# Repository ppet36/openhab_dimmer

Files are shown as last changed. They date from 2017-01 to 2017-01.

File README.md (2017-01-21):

# OpenHAB dimmer(s)

This repository contains simple dimmers for LED lighting based on potentiometer or cheap
chinese RF LED controller such as
http://www.ebay.com/itm/Mini-12V-RF-Wireless-Remote-Switch-Controller-Dimmer-for-LED-Strip-Light.

As always is there Cadsoft's Eagle schematic, PCB and firmware for ESP8266 that can be programmed using Arduino IDE.
Potentiometer version uses Average library https://github.com/MajenkoLibraries/Average for nice fade efect and jitter elimination.

Both dimmers are based on MOSFET transistor at output and cheap DC/DC converter with LM2596 from eBay (set at 3.3V!!!) for powering ESP.
In my case i used IPA040N06N with 0.004ohm resistance in threshold state. PWM frequency is set only to 120Hz so any MOSFET with
reasonable parameters can be used.

Like other my OpenHAB projects is there set of default parameters in firmare as well as HTML configuration interface at IP address of device.

## Potentiometer version
Potentiometer version uses in my case slider potentiometer and ESP07 with ADC input.
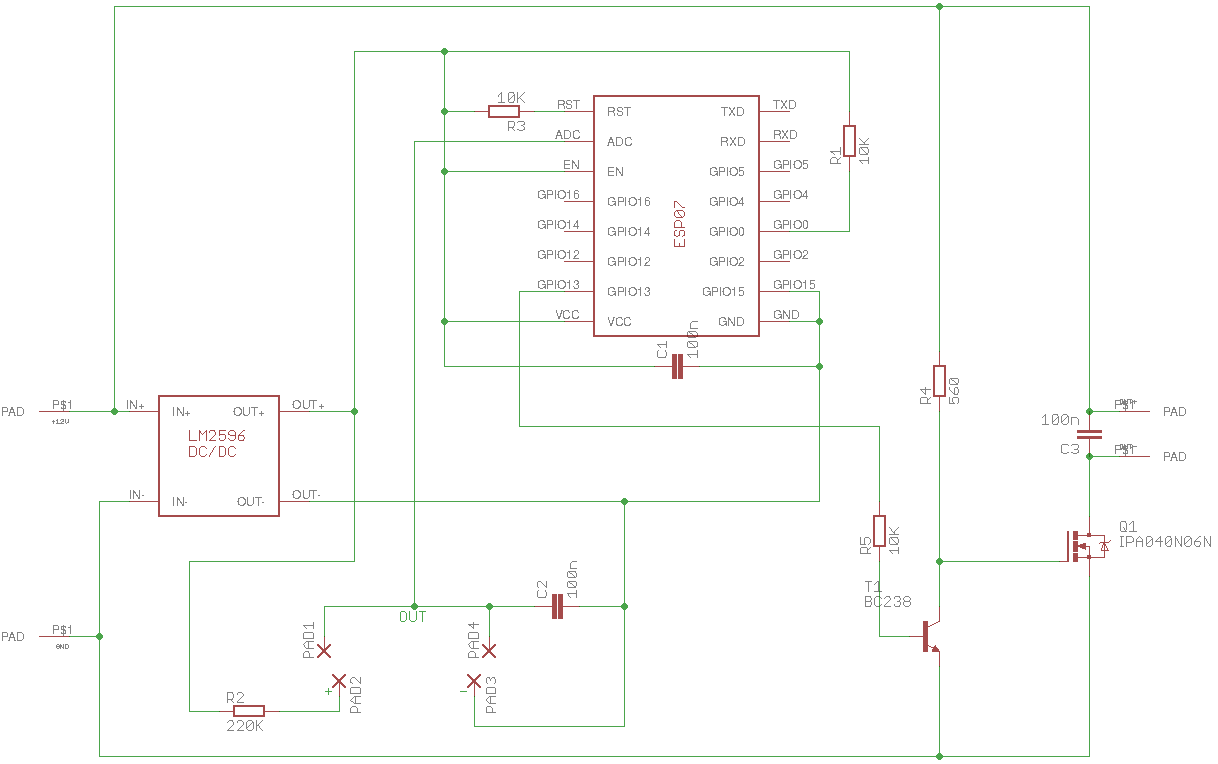
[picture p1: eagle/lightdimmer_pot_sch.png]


## RF version
RF version uses standard receiver available from eBay such as http://www.ebay.com/sch/i.html?_nkw=433mhz+receiver. Remote control codes can be set in firmware. This version uses my favorite ESP01 :)
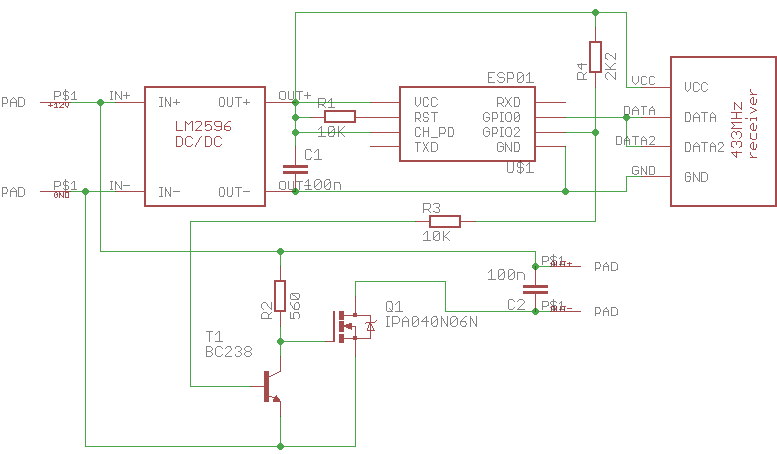
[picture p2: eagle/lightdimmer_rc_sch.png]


## Some project images
### RF version
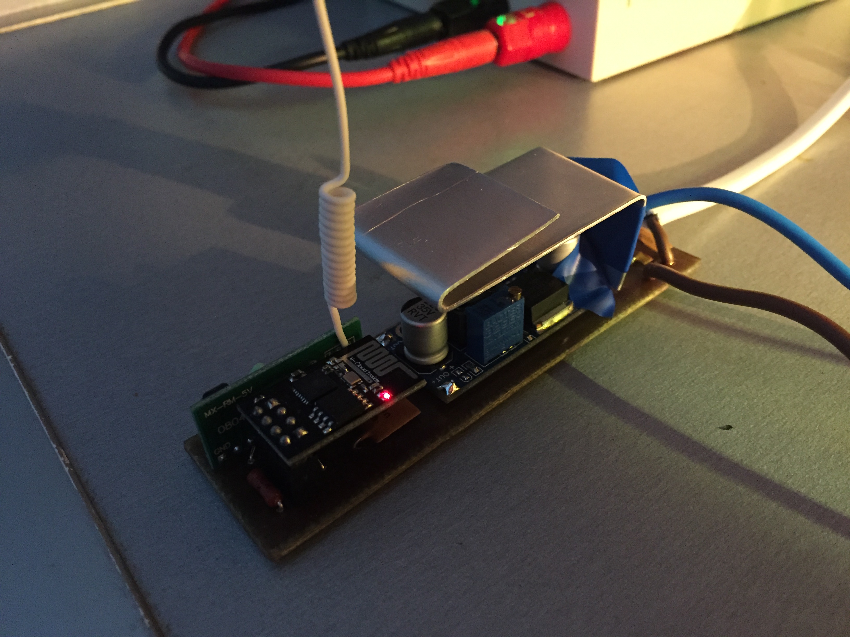
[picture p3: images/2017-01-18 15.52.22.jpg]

### POT version
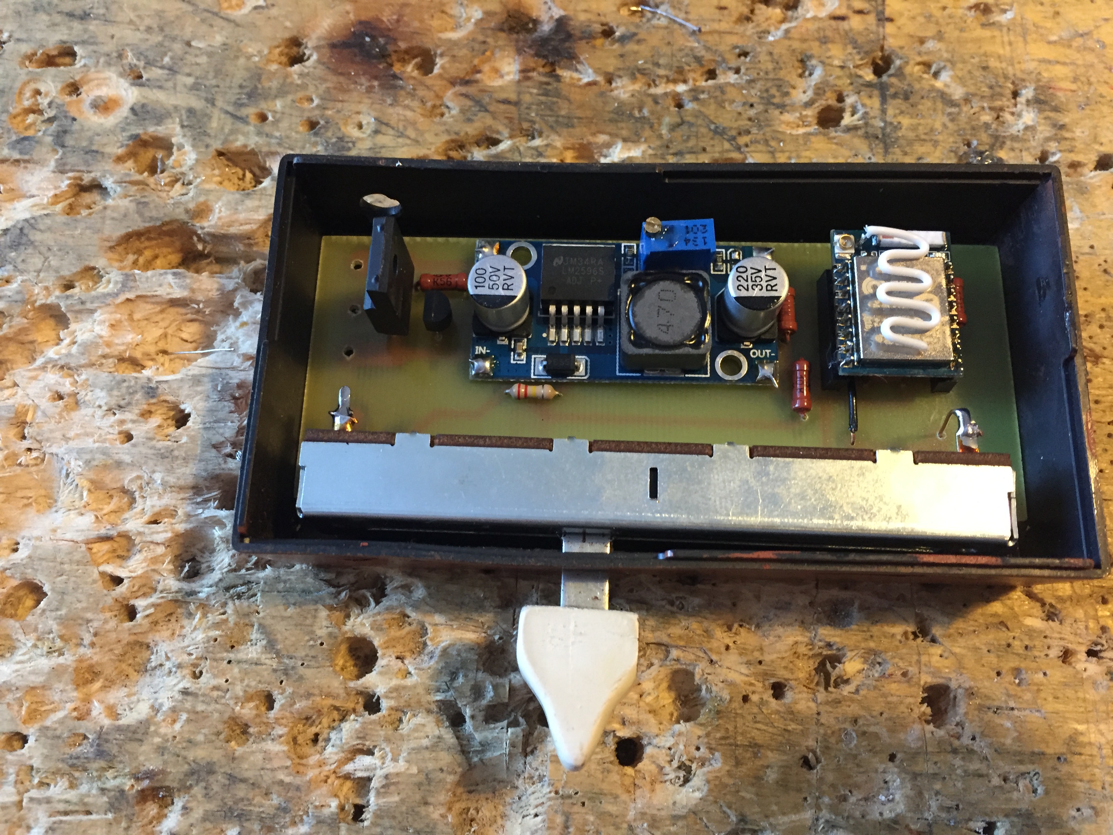
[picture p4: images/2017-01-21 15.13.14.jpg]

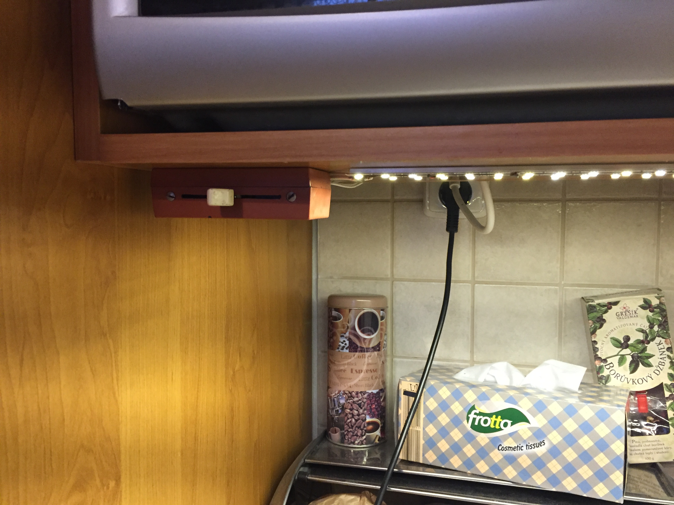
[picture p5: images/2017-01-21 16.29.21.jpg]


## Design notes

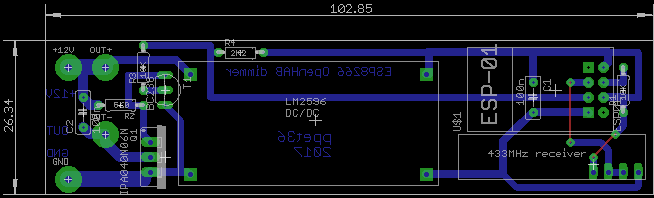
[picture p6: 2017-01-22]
eagle/lightdimmer_rc_brd.png

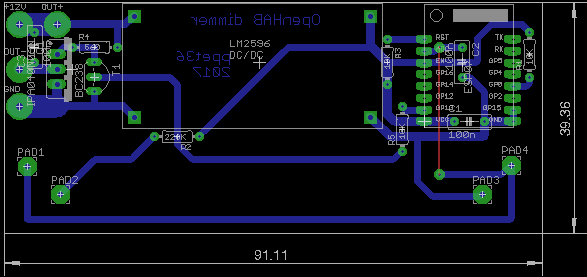
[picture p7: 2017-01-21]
eagle/lightdimmer_pot_brd.png

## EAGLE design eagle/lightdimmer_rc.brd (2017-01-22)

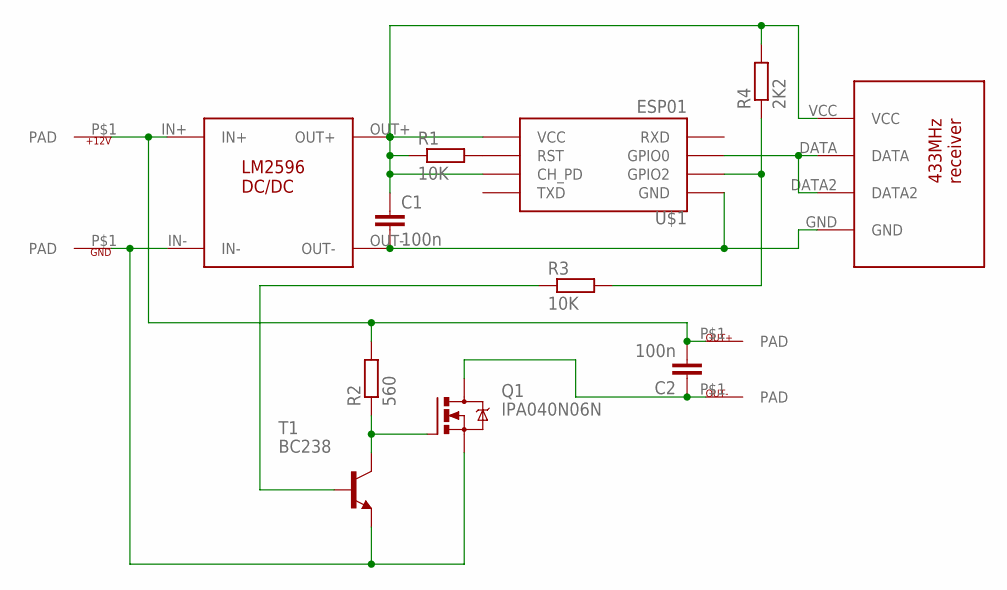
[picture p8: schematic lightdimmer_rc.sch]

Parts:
+12V: PAD
C1, C2: 100n; C050-025X075
GND: PAD
OUT+: PAD
OUT-: PAD
Q1: IPA040N06N; TO220BV
R1, R3: 10K; 0204/7
R2: 560; 0204/7
R4: 2K2; 0204/7
T1: BC238; TO92-CBE
U$1: ESP01
U$2: RECV433MHZ
U$3: LM2596DCDC

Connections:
unnamed: C1.1, R1.1, R4.2, U$1.CH_PD, U$1.VCC, U$2.VCC, U$3.OUT+
unnamed: C1.2, U$1.GND, U$2.GND, U$3.OUT-
unnamed: U$1.GPIO0, U$2.DATA, U$2.DATA2
unnamed: C2.1, OUT-.P$1, Q1.D
unnamed: GND.P$1, Q1.S, T1.E, U$3.IN-
unnamed: Q1.G, R2.1, T1.C
unnamed: +12V.P$1, C2.2, OUT+.P$1, R2.2, U$3.IN+
unnamed: R3.2, R4.1, U$1.GPIO2
unnamed: R1.2, U$1.RST
unnamed: R3.1, T1.B

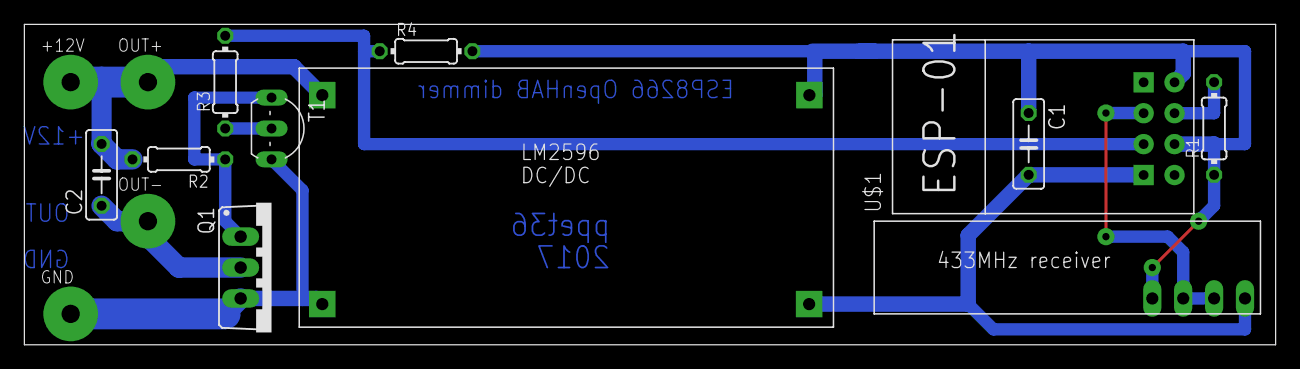
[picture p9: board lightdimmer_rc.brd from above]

Board: 2 copper layers, 102.8 x 26.3 mm, 15 parts (0 on the bottom side), 10 nets.

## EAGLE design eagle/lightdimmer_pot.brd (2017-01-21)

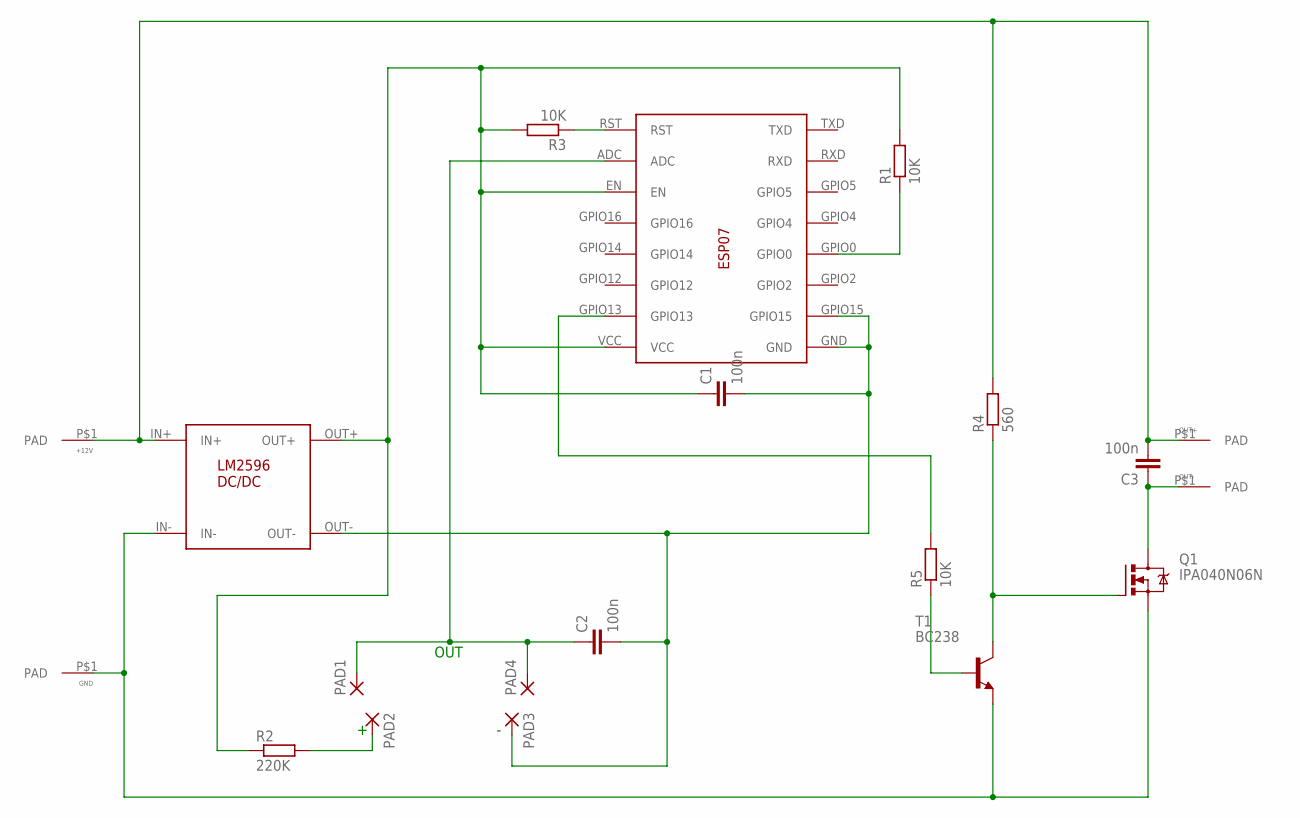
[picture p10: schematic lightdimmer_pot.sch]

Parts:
+12V: PAD
C1, C2, C3: 100n; C050-025X075
GND: PAD
OUT+: PAD
OUT-: PAD
PAD1, PAD2, PAD3, PAD4: WIREPAD3,17/1,1; 3,17/1,1
Q1: IPA040N06N; TO220BV
R1, R3, R5: 10K; 0204/7
R2: 220K; 0204/7
R4: 560; 0204/7
T1: BC238; TO92-CBE
U$1: LM2596DCDC
U$2: ESP07

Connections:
unnamed: GND.P$1, Q1.S, T1.E, U$1.IN-
unnamed: +12V.P$1, C3.2, OUT+.P$1, R4.2, U$1.IN+
unnamed: C3.1, OUT-.P$1, Q1.D
unnamed: C1.2, C2.2, PAD3.1, U$1.OUT-, U$2.GND, U$2.GPIO15
unnamed: C1.1, R1.2, R2.1, R3.2, U$1.OUT+, U$2.EN, U$2.VCC
unnamed: R5.2, U$2.GPIO13
unnamed: Q1.G, R4.1, T1.C
unnamed: C2.1, PAD1.1, PAD4.1, U$2.ADC
unnamed: R1.1, U$2.GPIO0
unnamed: R5.1, T1.B
unnamed: PAD2.1, R2.2
unnamed: R3.1, U$2.RST

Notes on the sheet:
OUT

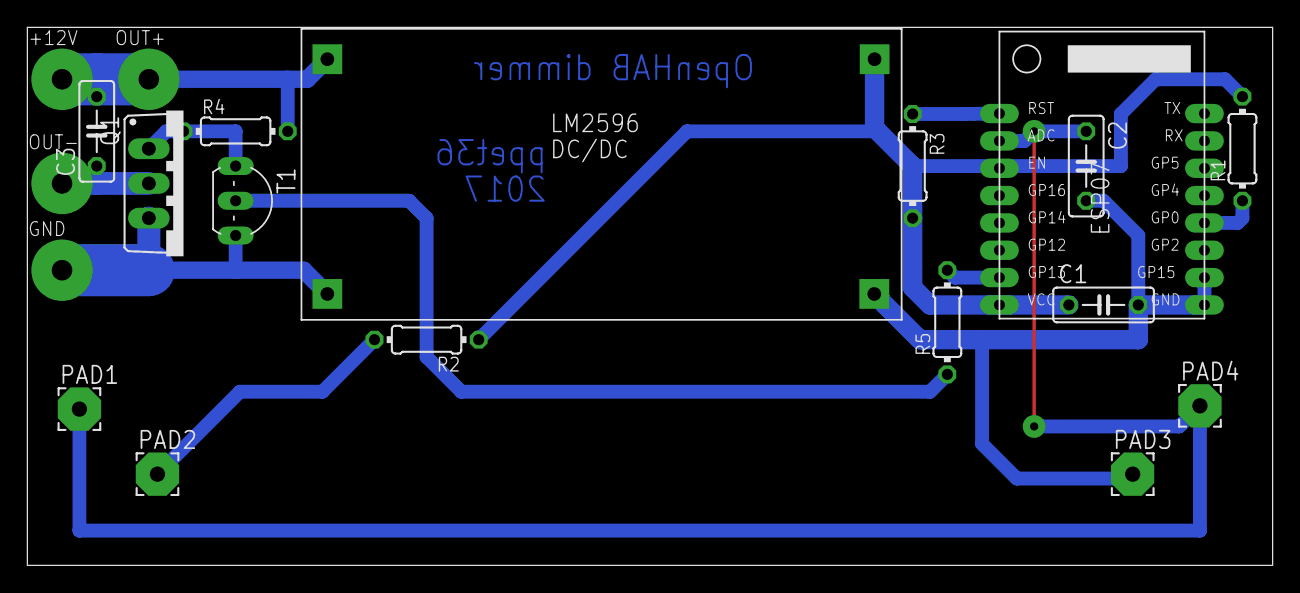
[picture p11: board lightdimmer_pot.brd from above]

Board: 2 copper layers, 91.1 x 39.4 mm, 20 parts (0 on the bottom side), 12 nets.

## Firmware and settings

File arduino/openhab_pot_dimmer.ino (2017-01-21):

/**
 * Simple OpenHAB dimmer based on ESP8266-07 module and potentiometer.
*/
#include <EEPROM.h>
#include <ESP8266WiFi.h>
#include <ESP8266HTTPClient.h>
#include <WiFiClient.h>
#include <ESP8266WebServer.h>
#include "Average.h"

// PIN, which is connected middle of potentiometer
#define POT_PIN  A0
// PWM adjusted pin which is connected to MOSFET gate.
#define PWM_PIN  13

// Local base URL of OpenHAB (can be changed later on config page)
#define DEFAULT_OPENHAB_HOST "192.168.128.100"
#define DEFAULT_OPENHAB_PORT 9000

// Name of OpenHAB item (can be changed later on config page)
#define DEFAULT_OPENHAB_ITEM "kitchenSideboard"

// Update time for item state in seconds;
// dimmer sends periodically its state to OpenHAB
#define ITEM_UPDATE_TIME 60L

// Local network definition; must have static IP address
#define LOCAL_IP   IPAddress(192, 168, 128, 204)
#define GATEWAY    IPAddress(192, 168, 128, 1)
#define SUBNETMASK IPAddress(255, 255, 255, 0)

// Local Wifi AP for connect
#define DEFAULT_WIFI_AP "******"
#define DEFAULT_WIFI_PASSWORD "*******"

// Error count for reconnect WIFI
#define ERR_COUNT_FOR_RECONNECT 30
#define HTTP_READ_TIMEOUT       10000
#define HTTP_CONNECT_TIMEOUT    5000

// Local WEB server port
#define WEB_SERVER_PORT 80

// Magic for detecting empty (unconfigured) EEPROM
#define MAGIC 0x44

// PWM frequuency.
#define PWM_FREQUENCY  120

// When potentiometer change value wait X millis before sending it to OpenHAB.
#define DEFAULT_OH_SEND_TIME 1000L

// POT ADC range
#define DEFAULT_MIN_POT_ADC_VAL 10
#define DEFAULT_MAX_POT_ADC_VAL 1020

// Sensitivity of potentiometer. When value is set from OpenHAB this is minimum change to accept value from potentiometer. In percent.
#define DEFAULT_POT_SENSITIVITY 10

// Nummer of values to average potentiometer. Elimitates jitter and added nice fade efect.
#define POT_AVERAGE_SIZE    500

// Configuration server
ESP8266WebServer *server = (ESP8266WebServer *) NULL;

// Number of communication errors
int errorCount = 0;

// Current light value (0-100) from OpenHAB
int openHabPwmVal = 0;

// Real PWM value is from potentiometer (true) or OpenHAB (false)
bool valFromPot = false;

// Last POT value for determining changes
int lastPotVal = -1;

// Averager for potentiometer vals
Average<int> potAv (POT_AVERAGE_SIZE);


/**
 * EEPROM configuration structure.
*/
struct OhConfiguration {
  int magic;
  char apName [24];
  char password [48];
  char openhabItem [50];
  char openhabHost [50];
  unsigned int openhabPort;
  unsigned int potSensitivity;
  unsigned int potMinAdcVal;
  unsigned int potMaxAdcVal;
  unsigned long openhabSendTime;
};

// Configuration
OhConfiguration config;


/**
 * Inicializes firmware.
*/
void setup() {
  Serial.begin (115200);

  // setup potentiometer pin
  pinMode (POT_PIN, INPUT);

  // setup PWM on output pin
  pinMode (PWM_PIN, OUTPUT);
  analogWriteFreq (PWM_FREQUENCY);
  setPwmVal (0);

  // read config from eeprom
  EEPROM.begin (sizeof (OhConfiguration));
  EEPROM.get (0, config);
  if (config.magic != MAGIC) {
    memset (&config, 0, sizeof (OhConfiguration));
    config.magic = MAGIC;
    updateConfigKey (config.apName, 24, String(DEFAULT_WIFI_AP));
    updateConfigKey (config.password, 48, String(DEFAULT_WIFI_PASSWORD));
    updateConfigKey (config.openhabItem, 50, String(DEFAULT_OPENHAB_ITEM));
    updateConfigKey (config.openhabHost, 50, String(DEFAULT_OPENHAB_HOST));
    config.openhabPort = DEFAULT_OPENHAB_PORT;
    config.potMinAdcVal = DEFAULT_MIN_POT_ADC_VAL;
    config.potMaxAdcVal = DEFAULT_MAX_POT_ADC_VAL;
    config.openhabSendTime = DEFAULT_OH_SEND_TIME;
    config.potSensitivity = DEFAULT_POT_SENSITIVITY;
  }

  // connect to WiFi and create HTTP server
  reconnectWifi();
  createServer();

  delay (1000);

  // Send current light state to OpenHAB; initialy is light off
  updateLightState (openHabPwmVal);
}

/**
 * Helper routine; updates config key.
 *
 * @param c key.
 * @param len max length.
 * @param val value.
*/
void updateConfigKey (char *c, int len, String val) {
  memset (c, 0, len);
  sprintf (c, "%s", val.c_str());
}

/**
 * Reconects WIFI.
*/
void reconnectWifi() {
  Serial.println ("WiFi disconnected...");
  WiFi.disconnect();
  String hostname = String("openhab_") + String(config.openhabItem);
  WiFi.hostname (hostname);
  WiFi.config (LOCAL_IP, GATEWAY, SUBNETMASK);
  WiFi.mode (WIFI_STA);
  delay (1000);

  Serial.print ("Connecting to "); Serial.print (WIFI_AP); Serial.print (' ');
  WiFi.begin (config.apName, config.password);
  delay (1000);
  while (WiFi.status() != WL_CONNECTED) {
    yield();
    delay (500);
    Serial.print (".");
  }
  delay (500);
  Serial.println();
  Serial.println ("WiFi connected...");
}

/**
 * Creates HTTP server.
*/
void createServer() {
  if (server) {
    server->close();
    delete server;
    server = NULL;
  }
  
  // ... and run HTTP server for setup
  server = new ESP8266WebServer (LOCAL_IP, WEB_SERVER_PORT);
  server->on ("/", wsConfig);
  server->on ("/update", wsUpdate);
  server->on ("/reconnect", wsReconnect);
  server->onNotFound (wsUpdatePwmLevel);
  server->begin();

  Serial.println ("Created server...");
}

/**
 * Updates PWM level of light
*/
void wsUpdatePwmLevel() {
  yield();
  
  String url = server->uri();

  Serial.println();
  Serial.print ("GET "); Serial.println (url);

  int pom = url.lastIndexOf ('/');
  if (pom > -1) {
    String val = url.substring (pom + 1);

    for (pom = 0; pom < val.length(); pom++) {
      if (!isDigit (val [pom])) {
        server->send (400, "text/plain", "Bad request");
        return;
      }
    }

    int newVal = (int)constrain (val.toInt(), 0, 100);
    Serial.print ("Update light level to "); Serial.print (newVal); Serial.println ('%');
    
    if (openHabPwmVal != newVal) {
      Serial.println ("Setting value from OpenHAB...");
      openHabPwmVal = newVal;
      valFromPot = false;
    }
    
    server->send (200, "text/plain", "");
  } else {
    server->send (404, "text/plain", "Not found");
  }
}

/**
 * Configuration page.
*/
void wsConfig() {
  yield();

  String resp = "<html><head><title>OpenHAB dimmer configuration</title>";
  resp += "<meta name=\"viewport\" content=\"initial-scale=1.0, width = device-width, user-scalable = no\">";
  resp += "</head><body>";
  resp += "<h1>OpenHAB dimmer configuration</h1>";
  resp += "<form method=\"post\" action=\"/update\" id=\"form\">";
  resp += "<table border=\"0\" cellspacing=\"0\" cellpadding=\"5\">";
  resp += "<tr><td>AP SSID:</td><td><input type=\"text\" name=\"apName\" value=\"" + String(config.apName) + "\" maxlength=\"24\"></td><td></td></tr>";
  resp += "<tr><td>AP Password:</td><td><input type=\"password\" name=\"password\" value=\"" + String(config.password) + "\" maxlength=\"48\"></td><td></td></tr>";
  resp += "<tr><td>OpenHAB item:</td><td><input type=\"text\" name=\"openhabItem\" value=\"" + String(config.openhabItem) + "\" maxlength=\"50\"></td><td></td></tr>";
  resp += "<tr><td>OpenHAB IP address:</td><td><input type=\"text\" name=\"openhabHost\" value=\"" + String(config.openhabHost) + "\" maxlength=\"50\"></td><td></td></tr>";
  resp += "<tr><td>OpenHAB port:</td><td><input type=\"text\" name=\"openhabPort\" value=\"" + String(config.openhabPort) + "\"></td><td></td></tr>";
  resp += "<tr><td>Potentiometer sensitivity [%]:</td><td><input type=\"text\" name=\"potSensitivity\" value=\"" + String(config.potSensitivity) + "\"></td><td></td></tr>";
  resp += "<tr><td>Potentiometer MIN ADC value:</td><td><input type=\"text\" name=\"potMinAdcVal\" value=\"" + String(config.potMinAdcVal) + "\"></td><td></td></tr>";
  resp += "<tr><td>Potentiometer MAX ADC value:</td><td><input type=\"text\" name=\"potMaxAdcVal\" value=\"" + String(config.potMaxAdcVal) + "\"></td><td></td></tr>";
  resp += "<tr><td>Millis before sending to OpenHAB:</td><td><input type=\"text\" name=\"openhabSendTime\" value=\"" + String(config.openhabSendTime) + "\"></td><td></td></tr>";

  resp += "<tr><td colspan=\"3\" align=\"center\"><input type=\"submit\" value=\"Save\"></td></tr>";
  resp += "</table></form>";
  resp += "<p><a href=\"/reconnect\">Reconnect WiFi...</a></p>";
  resp += "</body></html>";

  server->send (200, "text/html", resp);
}

/**
 * Reconnects WiFi with new parameters.
*/
void wsReconnect() {
  yield();
  String resp = "<script>window.alert ('Reconnecting WiFi...'); window.location.replace ('/');</script>";
  server->send (200, "text/html", resp);
  reconnectWifi();
  createServer();
}

/**
 * Saves configuration.
*/
void wsUpdate() {
  yield();

  String apName = server->arg ("apName");
  String password = server->arg ("password");
  String openhabItem = server->arg ("openhabItem");
  String openhabHost = server->arg ("openhabHost");
  unsigned int openhabPort = atoi (server->arg ("openhabPort").c_str());
  unsigned int potMinAdcVal = atoi (server->arg ("potMinAdcVal").c_str());
  unsigned int potMaxAdcVal = atoi (server->arg ("potMaxAdcVal").c_str());
  unsigned long openhabSendTime = atol (server->arg ("openhabSendCycles").c_str());
  unsigned int potSensitivity = atoi (server->arg ("potSensitivity").c_str());
  
  if (apName.length() > 1) {
    updateConfigKey (config.apName, 24, apName);
    updateConfigKey (config.password, 48, password);
    updateConfigKey (config.openhabItem, 50, openhabItem);
    updateConfigKey (config.openhabHost, 50, openhabHost);
    config.openhabPort = openhabPort;
    config.potMinAdcVal = constrain (potMinAdcVal, 0, 1023);
    config.potMaxAdcVal = constrain (potMaxAdcVal, potMinAdcVal, 1023);
    config.openhabSendTime = constrain (openhabSendTime, 100, 60000);
    config.potSensitivity = constrain (potSensitivity, 0, 100);
  
    // store configuration
    EEPROM.begin (sizeof (OhConfiguration));
    EEPROM.put (0, config);
    EEPROM.end();
  
    String resp = "<script>window.alert ('Configuration updated...'); window.location.replace ('/');</script>";
    server->send (200, "text/html", resp);
  } else {
    server->send (200, "text/html", "");
  }
}

/**
 * Calls URL and reads response.
 * 
 * @param url url.
 * @return String response.
*/
String communicate (String url) {
  WiFiClient client;

  // connect to OpenHAB
  Serial.print ("Connecting to "); Serial.print (config.openhabHost); Serial.print (':'); Serial.print (config.openhabPort); Serial.println ("...");
  if (client.connect (config.openhabHost, config.openhabPort)) {
    // send request
    String req = String("GET ") + url + String (" HTTP/1.1\r\n")
      + String("Host: ") + String (config.openhabHost) + String ("\r\nConnection: close\r\n\r\n");
    client.print (req);
    Serial.print (req);

    bool isError = false;
    
    // wait HTTP_CONNECT_TIMEOUT for response
    unsigned long connectStartTime = millis();
    while (client.available() == 0) {
      if (millis() - connectStartTime > HTTP_CONNECT_TIMEOUT) {
        errorCount++;
        isError = true;
        break;
      }

      yield();
    }

    if (!isError) {
      Serial.print ("Reading response -> ");
      
      // read response lines
      unsigned long readStartTime = millis();

      int ch;
      String resp = "";
      while ((ch = client.read()) != -1) {
        resp += (char)ch;
        
        if (millis() - readStartTime > HTTP_READ_TIMEOUT) {
          errorCount++;
          isError = true;
          break;
        }

        yield();
      }

      Serial.println ("OK");
      
      client.stop();
      return resp;
    } else {
      Serial.println ("ERROR");
    }
  }
  client.stop();
  return String("");
}

/**
 * Updates light state on server.
 *
 * @param val value.
*/
void updateLightState (int val) {
  static int lastSendPwmVal = -1;
  yield();
  if (lastSendPwmVal != val) {
    communicate (String("/CMD?") + String(config.openhabItem) + String("=") + String(val));
    lastSendPwmVal = val;
  }
}

/**
 * Sets PWM value
 * 
 * @param val value.
*/
void setPwmVal (int val) {
  // PIN is inverted eq. 1023 is off.
  analogWrite (PWM_PIN, 1023 - map (val, 0, 100, 0, 1023));
}

/**
 * Returns potentiometer value (0-100).
 *
 * @return int value.
*/
int getPotVal() {
  int av = constrain (analogRead (POT_PIN), 0, 1023);
  // This delay is taken from this https://github.com/esp8266/Arduino/issues/1634 discussion. Thank You renno-bih and Internet :)
  delay (3);
  
  av = constrain (1023 - av, config.potMinAdcVal, config.potMaxAdcVal);

  // potentiometer track is divided into 25 level parts
  int resl = map (av, config.potMinAdcVal, config.potMaxAdcVal, 0, 25) * 4;
  if (resl < 0) {
    resl = 0;
  } else if (resl > 100) {
    resl = 100;
  }

  // average value
  potAv.push (resl);
  return potAv.mean();
}

/**
 * Handle requests. 
*/
void loop() {
  static unsigned long lastInteractionTime = 0L;
  static unsigned long lastOpenhabSendTime = millis();

  if (server) {
    server->handleClient();
  }

  int potVal = getPotVal();
  if (lastPotVal < 0) {
    lastPotVal = potVal;
  } else if (abs (potVal - lastPotVal) > config.potSensitivity) {
    Serial.println ("Setting value from potentiometer...");
    valFromPot = true;
  }

  if (valFromPot) {
    lastPotVal = potVal;
  }

  // interaction with OpenHAB once per ITEM_UPDATE_TIME
  if (millis() - lastInteractionTime > ITEM_UPDATE_TIME * 1000L) {
    if (WiFi.status() == WL_CONNECTED) {
      String resp = communicate (String("/rest/items/") + String(config.openhabItem) + String("/state"));

      // extract text response
      int lip = resp.lastIndexOf ('\n');
      resp = resp.substring (lip + 1);

      if (resp.startsWith (String("Un"))) {
        Serial.println ("Unknown value:");
        Serial.println (resp);
        Serial.println ("> updating state...");
        updateLightState (openHabPwmVal);
        errorCount = 0;
      } else {
        int level = resp.toInt();
        Serial.print ("Updating level to: "); Serial.print (level); Serial.println ('%');
        if (level != openHabPwmVal) {
          Serial.println ("Setting value from OpenHAB...");
          valFromPot = false;
          openHabPwmVal = level;
        }
        errorCount = 0;
      }
    } else {
      Serial.println ("Wifi not connected!");
      errorCount++;
    }
      
    // when error count reaches ERR_COUNT_FOR_RECONNECT, reconnect WiFi.
    if (errorCount > ERR_COUNT_FOR_RECONNECT) {
      errorCount = 0;
      reconnectWifi();
      createServer();
    }

    lastInteractionTime = millis();
  }

  // Update PWM by the potentiometer or OpenHAB value
  if (valFromPot) {
    setPwmVal (potVal);

    // Send potentiometer change once per openHabSendTime
    if (millis() - lastOpenhabSendTime > config.openhabSendTime) {
      openHabPwmVal = potVal;
      lastOpenhabSendTime = millis();
      updateLightState (potVal);
    }
  } else {
    setPwmVal (openHabPwmVal);
  }

  yield();
}
